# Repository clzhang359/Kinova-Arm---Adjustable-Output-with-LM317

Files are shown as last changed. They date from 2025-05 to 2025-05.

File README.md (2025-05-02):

# PCB for Adjusting the Voltage Output from the Kinova Arm End Effector with an LM317
_This repo was made by Connie L. Zhang at Georgia Tech at the SAFE Robotics Lab as a part of the Farmhand Project._

_Last Updated: 2025/05/02_

The 24V output of the Kinova Arm was too much for the microscope's motor (12V/1.5A), so the LM317 was applied to decrease the output voltage.

This PCB Design was made in KiCAD, and all design files can be found in the "kinova_arm_pcb_adjust" branch. The "fabexport_pwrpcb.zip" contains all the PCB manufacturing files.

This PCB goes on the Kinova Arm's End Effector and matches the provided pinout as shown below from the manual: 

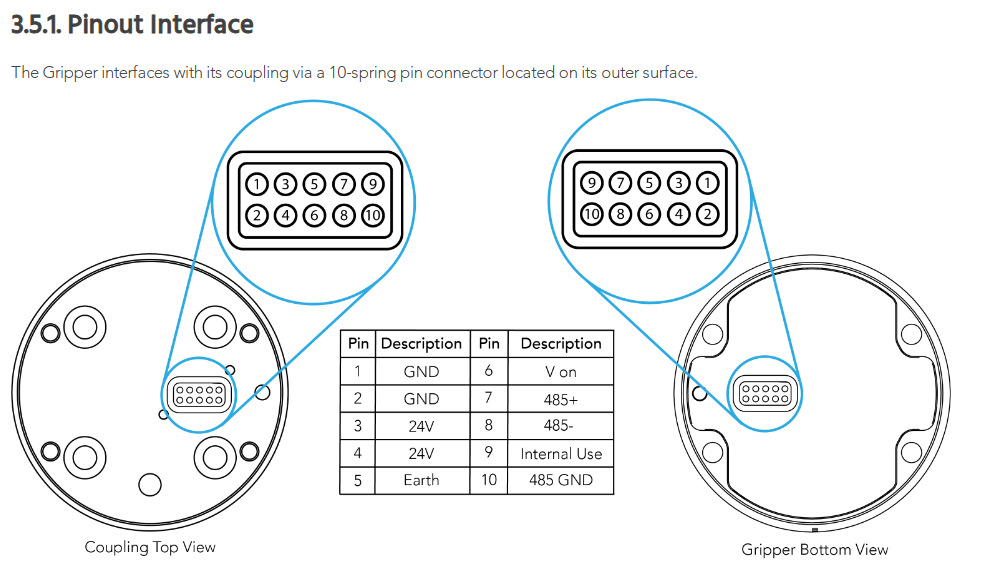
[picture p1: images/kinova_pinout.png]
End Effector Pinout


## Why the LM317?

This specific device was chosen since (a) it was available at the HIVE makerspace, (b) I have used this in a previous class, and (c) the project fit the application.

The [LM317](https://www.st.com/resource/en/datasheet/lm217.pdf) is an adjustable voltage regulator that can input up to 40V and output anywhere between the provided input and 1.25V and up to 1.5A.

This schematic was taken from the datasheet has protection diodes to prevent any input short circuit and capacitance short circuit during capacitance discharge.

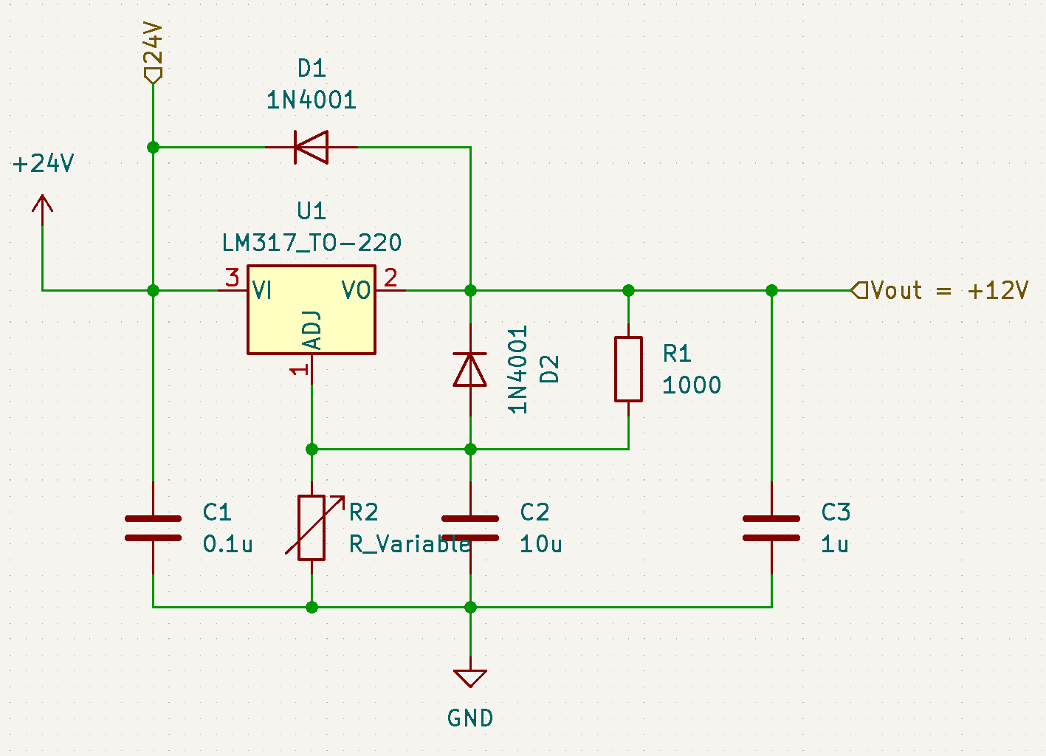
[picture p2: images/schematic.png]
PCB Schematic


## Should I use this PCB for my project with my Kinova Arm?

Firstly, how much voltage and current does your voltage require?
- If it requries **less than 24V & less than 1.5A**, then yes, you can use this PCB.
- If it requries **less than 1.25V**, then **do not** use this PCB design.
- If it requires **more than 1.5A**, then **do not** use this PCB design.
- If it requires **more than 24V & less than 1.5A**, then **do not** use the LM317 or this PCB.

## Parts List:
- 1 x LM317
- 1 x 0.1uF capacitor
- 1 x 10uF capacitor
- 1 x 1uF capacitor
- 2 x 1N4001 diodes
- 1 x 1kΩ resistor
- 1 x 3-prong 10kΩ variable resistor

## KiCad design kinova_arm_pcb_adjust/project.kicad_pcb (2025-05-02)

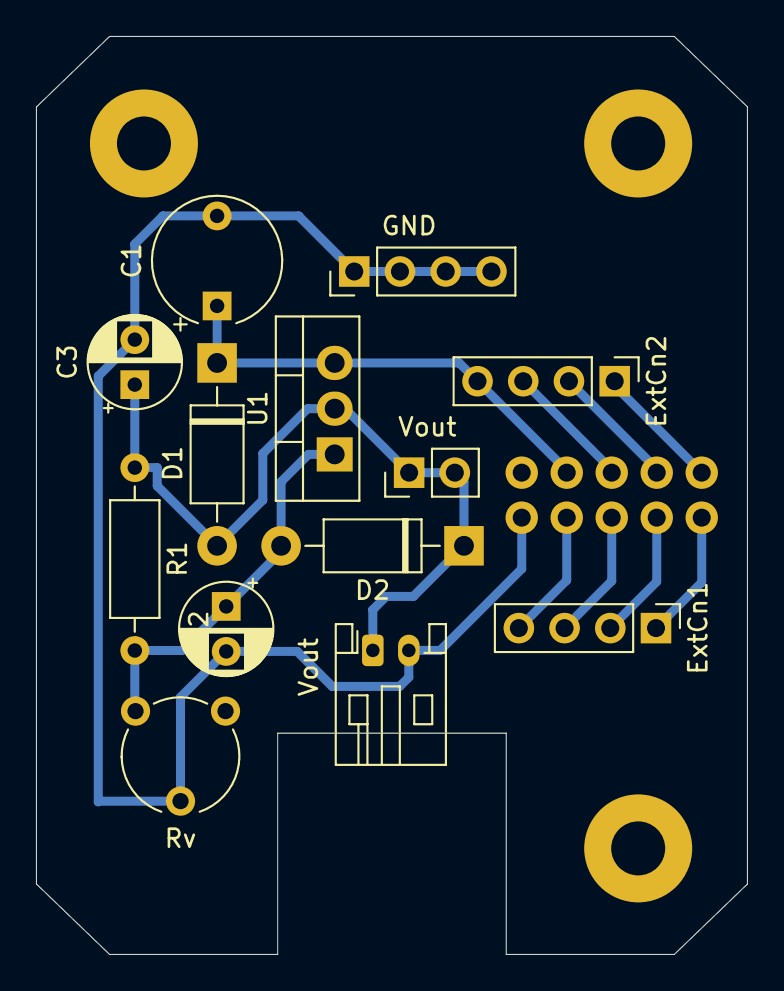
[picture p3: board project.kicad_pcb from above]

Board: 2 copper layers, 39.5 x 51.0 mm, 14 parts (1 on the bottom side), 10 nets.

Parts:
2x5_thr: 2x5_thr
C1: 0.1u; CP_Radial_Tantal_D7.0mm_P5.00mm
C2: 10u; CP_Radial_D5.0mm_P2.50mm
C3: 1u; CP_Radial_D5.0mm_P2.50mm
D1, D2: 1N4001; D_DO-41_SOD81_P10.16mm_Horizontal
ExtCn1, ExtCn2: PinHeader_1x04_P2.54mm_Vertical
GND: PinHeader_1x04_P2.54mm_Vertical
R1: 1000; R_Axial_DIN0207_L6.3mm_D2.5mm_P10.16mm_Horizontal
Rv: ClkWs-/CClkWs+; Potentiometer_Piher_PT-6-V_Vertical
U1: LM317_TO-220; TO-220-3_Vertical
Vout: JST_PH_S2B-PH-K_1x02_P2.00mm_Horizontal
Vout#2: PinHeader_1x02_P2.54mm_Vertical

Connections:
485 GND: 2x5_thr.6, ExtCn1.1
485+: 2x5_thr.2, ExtCn2.2
485-: 2x5_thr.7, ExtCn1.2
+24V: 2x5_thr.4, 2x5_thr.9, C1.1, D1.1 (K), ExtCn1.4, ExtCn2.4, U1.3 (VI)
/Vout = +12V: C3.1, D1.2 (A), D2.1 (K), R1.1, U1.2 (VO), Vout.1, Vout#2.2
Earth: 2x5_thr.3, ExtCn2.3
GND: 2x5_thr.5, 2x5_thr.10, C1.2, C2.2, C3.2, GND.1, GND.2, GND.3, GND.4, Rv.2, Vout.2
Intern: 2x5_thr.1, ExtCn2.1
unnamed: C2.1, D2.2 (A), R1.2, Rv.1, U1.1 (ADJ)
Von: 2x5_thr.8, ExtCn1.3
